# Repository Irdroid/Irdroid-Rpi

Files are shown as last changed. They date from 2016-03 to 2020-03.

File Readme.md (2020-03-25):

# Irdroid-Rpi Infrared Transceiver for Raspberry Pi

The latest gadget that we are working on is the Irdroid-Rpi Infrared Transceiver HAT / Add-on board for Raspberry Pi. The board provides Infrared Transmitter , Infrared Receiver and UEXT interconnect for Olimex sensors and boards designed with the UEXT connector. The board can be stacked on top of the Rpi board and you could turn your Rpi into a fully functional Infrared remote control for you home infrared consumer electronics. The Irdroid-Rpi is compatible with the LIRC/ Lirc GPIO driver for raspberry Pi and the LIRC utilities for recording and transmitting infrared signals can be used. The Irdroid-Rpi uses a optical IR amplification technique that allows to transmit high power IR signal by signal amplification after the IR light is emitted.

- Infrared Transceiver add-on / HAT for Raspberry Pi
- Infrared Transmitter @940nm with 10+ meters range
- Infrared Receiver up to 40khz and 10+ meters of receive range
- On-board UEXT Interconnect for connecting Olimex sensors and boards.
- Open Source Hardware.

### Version
1.0

### Installation Instructions

Detailed Installation Instructions https://irdroid.eu/wp-content/uploads/2020/03/Irdroid-Rpi-Installation-Guide.txt

### Grab a sample

You can grab a sample board from http://www.irdroid.eu/irdroid-rpi-infrared-transceiver-raspberry-pi/
### Tech

The Irdroid-Rpi infrared transceiver for Raspberry Pi is also designed with the possibility to connect sensors and boards from Olimex (http://www.olimex.com) by using the on-board UEXT connector, designed by Olimex. You can check here what sensors are supported https://www.olimex.com/Products/Components/Sensors/ .

### Todos

 - Add holders for the infrared leds in schematic
 
### Updates

Irdroid-Rpi now has a DT Overlay support via the on-board eeprom that now ships with every board. Once attached to a Raspberry Pi, the Irdroid-Rpi Hat will be recognized automatically, it will set the board inputs and outputs, and it will load the appropriate Kernel LIRC-RPI drivers. This feature improoves user experience and it provides plug-n-play support for the Product. The user will only have to install lircd (if not shipped by default with the distribution used).

The Irdroid-Rpi board details such as Vendor and Product IDs are available in 

/proc/device-tree/hat

To query Product & Vendor use:

$ more product  

$ more vendor

License
----
GPL 2.0

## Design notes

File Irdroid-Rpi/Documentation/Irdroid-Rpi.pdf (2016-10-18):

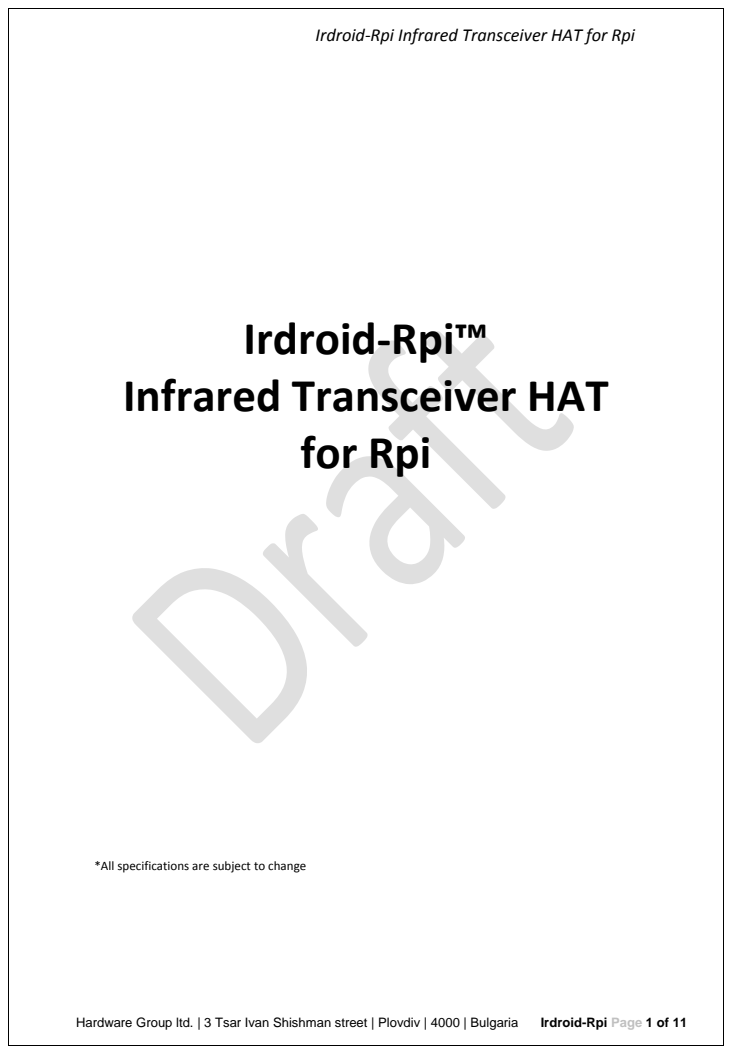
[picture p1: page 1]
Hardware Group ltd. | 3 Tsar Ivan Shishman street | Plovdiv | 4000 | Bulgaria; Irdroid-Rpi Page 1 of 11; for Rpi

Irdroid-Rpi Infrared Transceiver HAT for Rpi

Irdroid-Rpi™
Infrared Transceiver HAT

*All specifications are subject to change

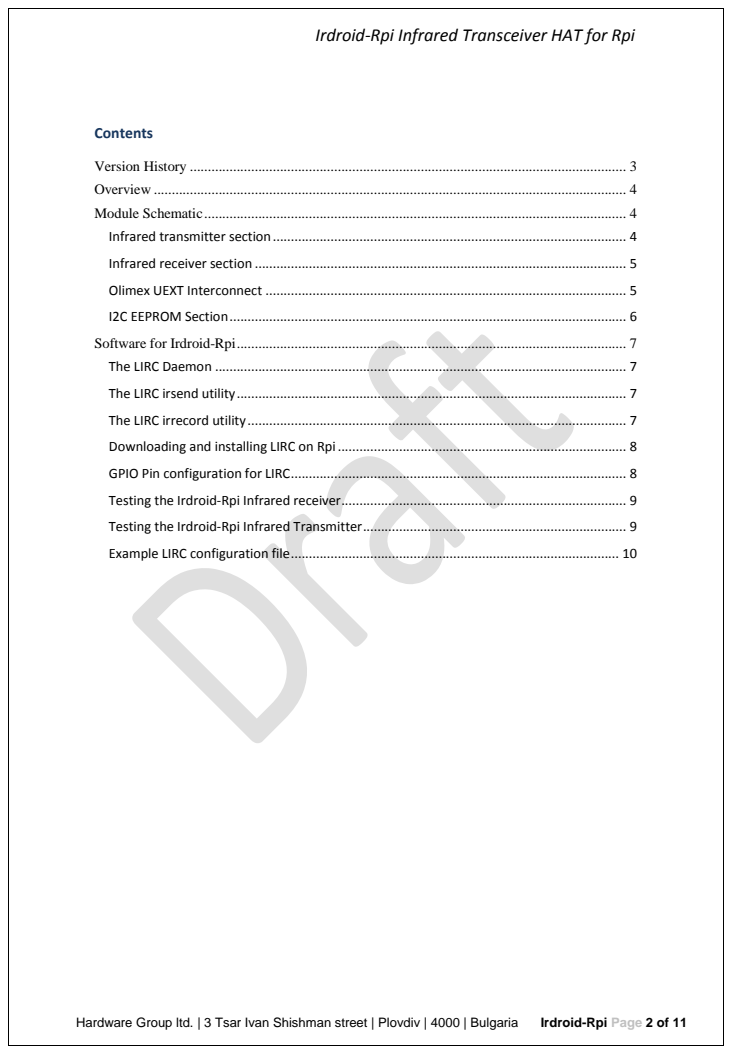
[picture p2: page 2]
Hardware Group ltd. | 3 Tsar Ivan Shishman street | Plovdiv | 4000 | Bulgaria; Irdroid-Rpi Page 2 of 11; Contents

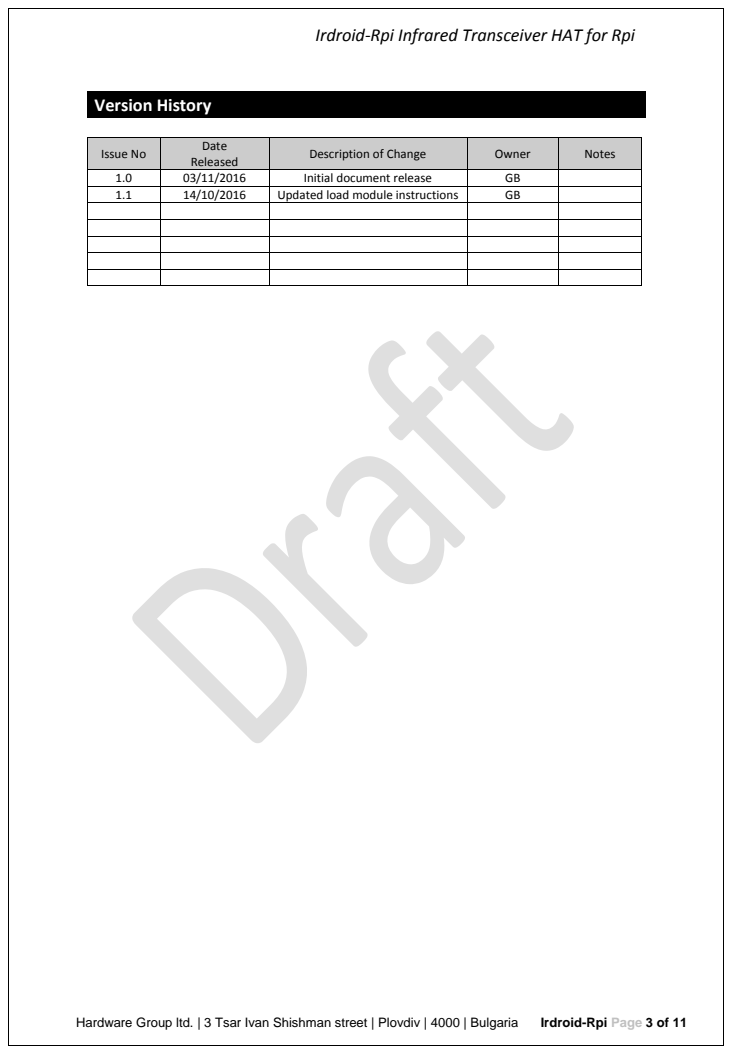
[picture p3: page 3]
Hardware Group ltd. | 3 Tsar Ivan Shishman street | Plovdiv | 4000 | Bulgaria; Irdroid-Rpi Page 3 of 11; Version History

Issue No | Date Released | Description of Change | Owner | Notes

1.0 | 03/11/2016 | Initial document release | GB
1.1 | 14/10/2016 | Updated load module instructions | GB

Hardware Group ltd. | 3 Tsar Ivan Shishman street | Plovdiv | 4000 | Bulgaria Irdroid-Rpi Page 4 of 11

Overview

The Irdroid-Rpi™ is a Infrared Transceiver stackable board or the so called HAT for Raspberry Pi . The Irdroid-Rpi™ allows both transmitting and receiving of infrared signals. The Irdroid-Rpi™ Infrared transmitter part is wired with three powerful infrared LEDs which emit infrared signals @ the commonly used infrared wavelength of 940nm. The module is designed and uses optical signal amplification, which combines the Infrared light emitted by the three infrared led's and significantly increases the infrared transmitting range.

The board interface with the Raspberry Pi is a 2x20 pin female header connector. Two GPIOs are used to control the Transmitter and Receiver part. The board also provides an Interface to the Olimex development boards and sensors via the Olimex's UEXT connector. The connector is wired following the Olimex recommendations for wiring a UEXT Host. The UEXT interconnect provides 2 Serial interfaces ( 1xUART and 1xSPI ), 1 I2C interface and 3.3V supply.
The Irdroid-Rpi™ board also has a place for a I2C EEPROM memory which is optional and not installed by default. The Irdroid-Rpi™ board in combination with LIRC for raspberry Pi can be used to control your home infrared consumer electronics like TVs, DVDs, Air-conditioners and even more.

Module Schematic

Below are the sections from the schematic responsible for the different actions like, Infrared transmitting, infrared receiving, I2C EEPROM and Olimex UEXT Interconnect section.

Infrared transmitter section

The image on the left shows the infrared transmitter section. The transmitter is powered by the Rpi 5V supply pins. We have envisaged alternative power supply in case the user decides to alter the schematic or change Infrared Leds. The jumper J2 is normally shorted and the Infrared Transmitter section is supplied with 5V DC from the Rpi board. There is a possibility to supply the board with a external 5V power supply by disconnecting jumper J2 and shorting the "EXT" jumper. As mentioned above the schematic allows for optical amplification of the transmitted infrared signal which increases the infrared range. The Infrared transmitter is controlled by the Rpi pin 11 (GPIO17).

Hardware Group ltd. | 3 Tsar Ivan Shishman street | Plovdiv | 4000 | Bulgaria Irdroid-Rpi Page 5 of 11

Infrared receiver section

The Infrared Receiver section consist of custom infrared receiver IC and it is supplied via the Raspberry Pi 3.3V power supply.

The infrared receiver IC can receive infrared signals @ up to 40khz which is the most common frequency used for consumer electronics infrared remote control.

The Infrared receiver IC DATA output pin is wired to the RPI pin 12 (GPIO18).

If required the user could de-solder and use a different Infrared Receiver IC of his choice.

Olimex UEXT Interconnect

The Irdroid-Rpi™ Infrared Transceiver HAT is equipped with a Olimex UEXT connector that would allow the users to connect various sensors and devices available for purchase from Olimex website - http://www.olimex.com .

The Olimex UEXT is wired for HOST mode which means that the UART RX/TX pins should be crossed at device end of the connection.

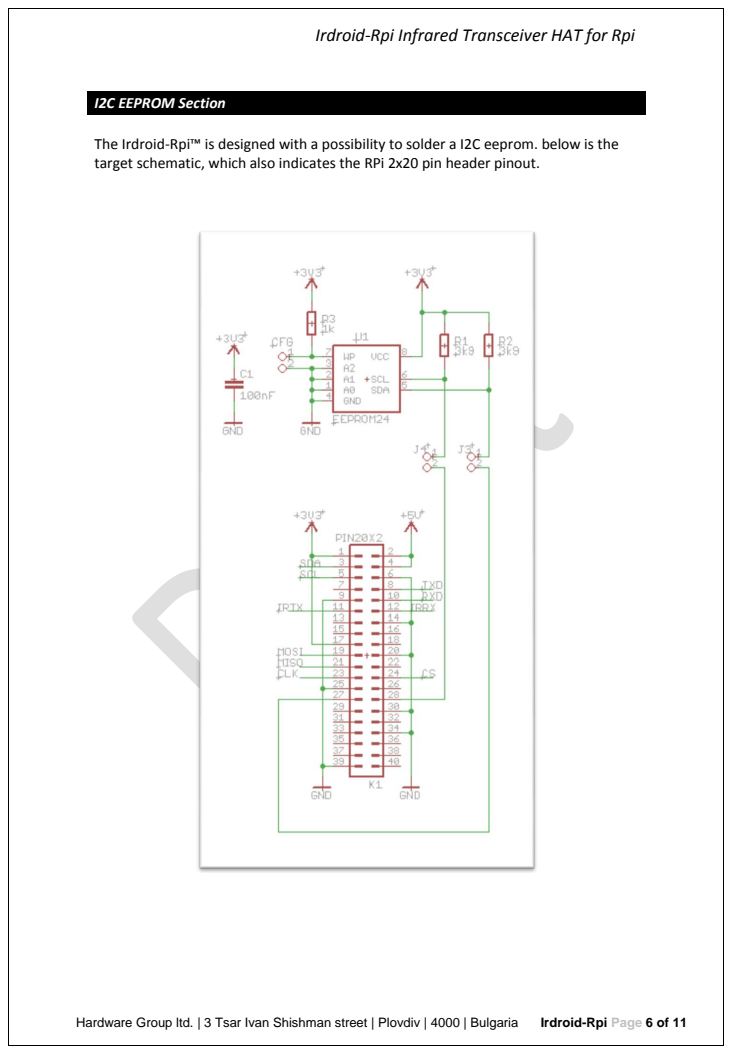
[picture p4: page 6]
Hardware Group ltd. | 3 Tsar Ivan Shishman street | Plovdiv | 4000 | Bulgaria; Irdroid-Rpi Page 6 of 11; I2C EEPROM Section

The Irdroid-Rpi™ is designed with a possibility to solder a I2C eeprom. below is the
target schematic, which also indicates the RPi 2x20 pin header pinout.

Hardware Group ltd. | 3 Tsar Ivan Shishman street | Plovdiv | 4000 | Bulgaria Irdroid-Rpi Page 7 of 11

Software for Irdroid-Rpi

The Irdroid-Rpi Infrared Transceiver HAT is designed for Rpi and the software that is commonly used is LIRC (Linux Infrared Remote control - see http://www.lirc.org). By using LIRC the user gets access to more than 2000+ already digitized infrared remote control codes that are in the LIRC database of supported remotes. The LIRC Software package is available for Almost any distribution of Linux. In this Manual we will describe the case of using the Linux Distribution for Rpi - Raspbian.

A detailed information and howtos for lirc can be found @ http://www.lirc.org .

The LIRC software packages has a number of utilities responsible for different actions like infrared transmitting, infrared receiving , serving the data to a socket.

The LIRC Daemon

The LIRC Daemon is a Linux daemon that runs as a process in linux and takes care of the data received via the device drivers and routes that data to a TCPIP Socket. It also listens for commands sent via Socket on a Specific port. The Lirc daemon runs in the background and it provides an interface to the infrared remote control application (LIRC Client). There are many Lirc clients , for Android , IOS, Linux and Windows.

The LIRC irsend utility

The irsend utility is used to transmit infrared commands to your target infrared equipment to be controlled like TVs , STBs , Air-con etc. The utility communicates with the LIRC daemon. The Utility has the following example syntax:

> irsend SEND_ONCE SAMSUNG_TV power

The above command send the command "power" for Device "Samsung_TV" and send it once with no repeat.

The Device should be available in the LIRC configuration file in order for the above command to be executed.

The LIRC irrecord utility

The program will allow you to record infrared commands from your existing remote control and create a LIRC configuration file for this particular remote control.

In order to use it you should make sure that the lircd is not working. Simply issue:

> sudo killall lircd

Hardware Group ltd. | 3 Tsar Ivan Shishman street | Plovdiv | 4000 | Bulgaria Irdroid-Rpi Page 8 of 11
> irrecord --list-namespace | grep KEY

Downloading and installing LIRC on Rpi

The LIRC software package can be downloaded and installed using the apt-get command :

> sudo apt-get install lirc
> sudo apt-get install lirc-x

GPIO Pin configuration for LIRC

The default gpio pins for the application are:

input pin for receiving infrared signals: PIN12/GPIO18
output pin for transmitting ir signals is : PIN11/GPIO17

The above default configuration is compatible with Irdroid-Rpi so practically you should not change it. There is a way to change the default pins by issuing the following command :

> modprobe lirc_rpi gpio_in_pin=18 gpio_out_pin=17

If the modprobe gives you an error , that the module cant be loaded due to the fact that the device is missing, then edit the file /boot/config.txt and uncomment the "dtoverlay=lirc-rpi" , save the changes and reboot your raspberry Pi . After the above changes you should have a /dev/lirc0 device, and you should be able to load the lirc_rpi module.

You could also edit the /etc/modules and change the pins there :

lirc_dev
lirc_rpi gpio_in_pin=18 gpio_out_pin=17

Edit your /etc/lirc/hardware.conf file as follows: > sudo su
> cd /etc/lirc
> sudo /leafpad hardware.conf
or
> sudo /leafpad /etc/lirc/hardware.conf

######################################################## # /etc/lirc/hardware.conf

# Arguments which will be used when launching lircd LIRCD_ARGS="--uinput --listen"

Hardware Group ltd. | 3 Tsar Ivan Shishman street | Plovdiv | 4000 | Bulgaria Irdroid-Rpi Page 9 of 11

# Don't start lircmd even if there seems to be a good config file # START_LIRCMD=false

# Don't start irexec, even if a good config file seems to exist.

# START_IREXEC=false

# Try to load appropriate kernel modules LOAD_MODULES=true

# Run "lircd --driver=help" for a list of supported drivers. DRIVER="default"

# usually /dev/lirc0 is the correct setting for systems using udev DEVICE="/dev/lirc0"

MODULES="lirc_rpi"
# Default configuration files for your hardware if any LIRCD_CONF=""

LIRCMD_CONF=""
5 of 9

Restart lircd so it picks up these changes:
sudo /etc/init.d/lirc restart

Testing the Irdroid-Rpi Infrared receiver

Once the the configurations described above are completed you can test the Infrared Receiver. To do that you need to stop the LIRC daemon by issuing the following command:

> sudo /etc/init.d/lirc stop
> sudo modprobe lirc_rpi
> sudo mode2 -d /dev/lirc0

the aboe commands first stop the lirc daemon , then it loads the lirc_rpi device driver module to the linux kernel and finally runs the program mode2 to show the mark - space of an infrared singal.

Now you could point a remote control toward the Irdroid-Rpi and press some buttons. You should be able to see similar output in the console as below:

space 402351
pulse 135
space 7085
pulse 85
space 2903

Testing the Irdroid-Rpi Infrared Transmitter

In order to test the Irdroid-Rpi infrared transmitter part you need to get a lirc configuration file for the target infrared equipment to be controlled . You can try

Hardware Group ltd. | 3 Tsar Ivan Shishman street | Plovdiv | 4000 | Bulgaria Irdroid-Rpi Page 10 of 11 searching in the LIRC database of remotes available at http://lirc.sf.net/remotes .
You could also generate a lirc conf file by recording the buttons of your remote control.

# You must stop lirc to free up /dev/lirc0 by issuing the following command

> sudo /etc/init.d/lirc stop
# Create a new remote control configuration file (using /dev/lirc0) and save the output to ~/lircd.conf

> irrecord -d /dev/lirc0 ~/lircd.conf

# Make a backup of the original lircd.conf file

>sudo mv /etc/lirc/lircd.conf /etc/lirc/lircd_original.conf

# Copy over your new configuration file

>sudo cp ~/lircd.conf /etc/lirc/lircd.conf

# Start up lirc again

>sudo /etc/init.d/lirc start

Once you’ve completed a remote configuration file save/add it to /etc/lirc/lircd.conf

Now you can use the irsend application that comes with the LIRC package for linux and you can issue a command using the syntax below:

> irsend SEND_ONCE Remote_Name Remote_Button

You could also download other remote control configuration files from the database of existing digitized remotes available at http://lirc.sf.net/remotes.

Example LIRC configuration file

The LIRC configuration file is used to store remote control codes either in RAW space pulse format or decoded HEX values, depending on the remote control protocol. Below is a example configuration file for TESY home panel heater unit.

# Please make this file available to others

# by sending it to <lirc@bartelmus.de>

# this config file was automatically generated

# using lirc-0.9.0(IRToy) on Thu Sep 17 21:47:15 2015 #

# contributed by

# brand: | Tesy

# model no. of remote control:

# devices being controlled by this remote: #

begin remote

name Tesy
bits | 16
flags SPACE_ENC
eps | 30
aeps | 100

Hardware Group ltd. | 3 Tsar Ivan Shishman street | Plovdiv | 4000 | Bulgaria | Irdroid-Rpi Page 11 of 11
header | 8969 4395
one | 599 1607
zero | 599 | 489
ptrail | 604
repeat | 8981 2156
pre_data_bits | 16
pre_data | 0xFF
gap | 39670
repeat_gap | 95433
toggle_bit_mask 0x0
| begin codes
power | 0x50AF
plus | 0x20DF
minus | 0xE01F
timer | 0xF807
temp | 0x08F7
end codes

end remote

As you can see there are specific section for every remote in this file which means that you can have multiple remotes defined in lircd.conf file .

The "begin remote" section defines the section start for a new remote control and the "end remote" section end for the remote . You can have as many remotes as you want defined in a single configuration file.

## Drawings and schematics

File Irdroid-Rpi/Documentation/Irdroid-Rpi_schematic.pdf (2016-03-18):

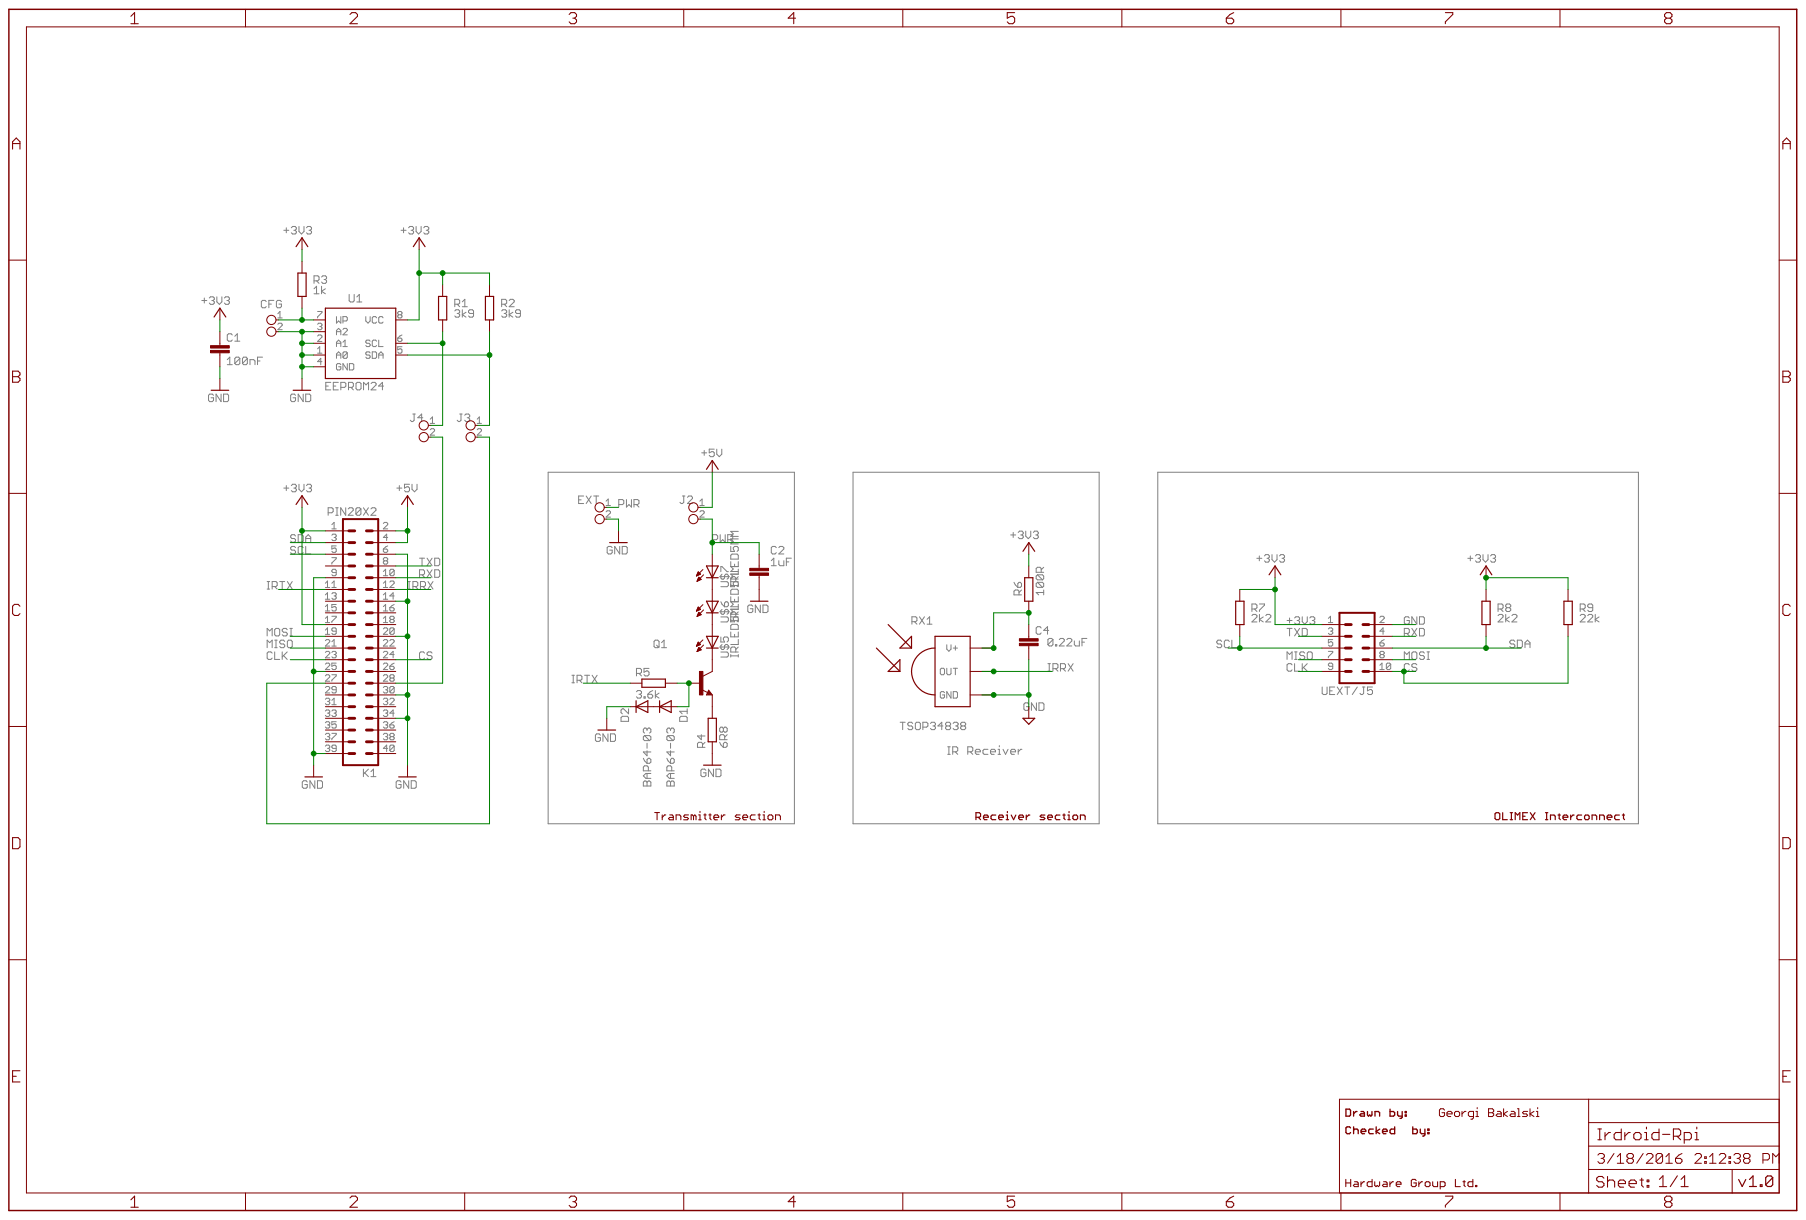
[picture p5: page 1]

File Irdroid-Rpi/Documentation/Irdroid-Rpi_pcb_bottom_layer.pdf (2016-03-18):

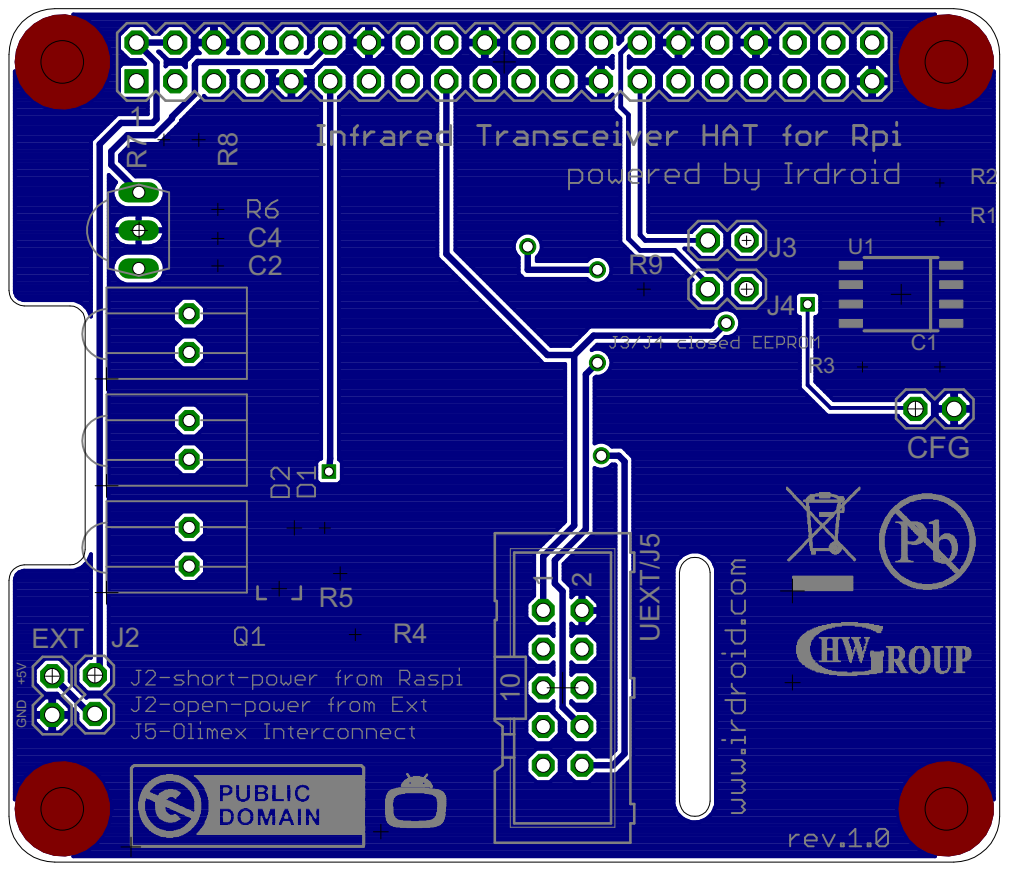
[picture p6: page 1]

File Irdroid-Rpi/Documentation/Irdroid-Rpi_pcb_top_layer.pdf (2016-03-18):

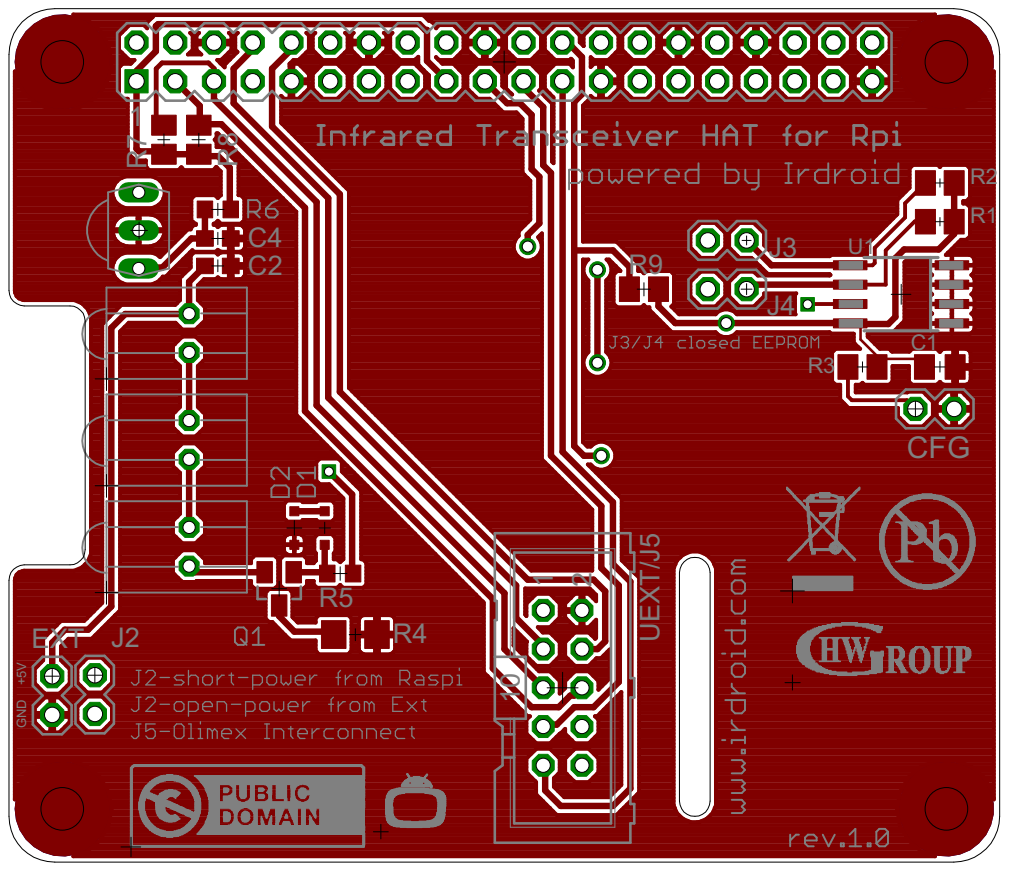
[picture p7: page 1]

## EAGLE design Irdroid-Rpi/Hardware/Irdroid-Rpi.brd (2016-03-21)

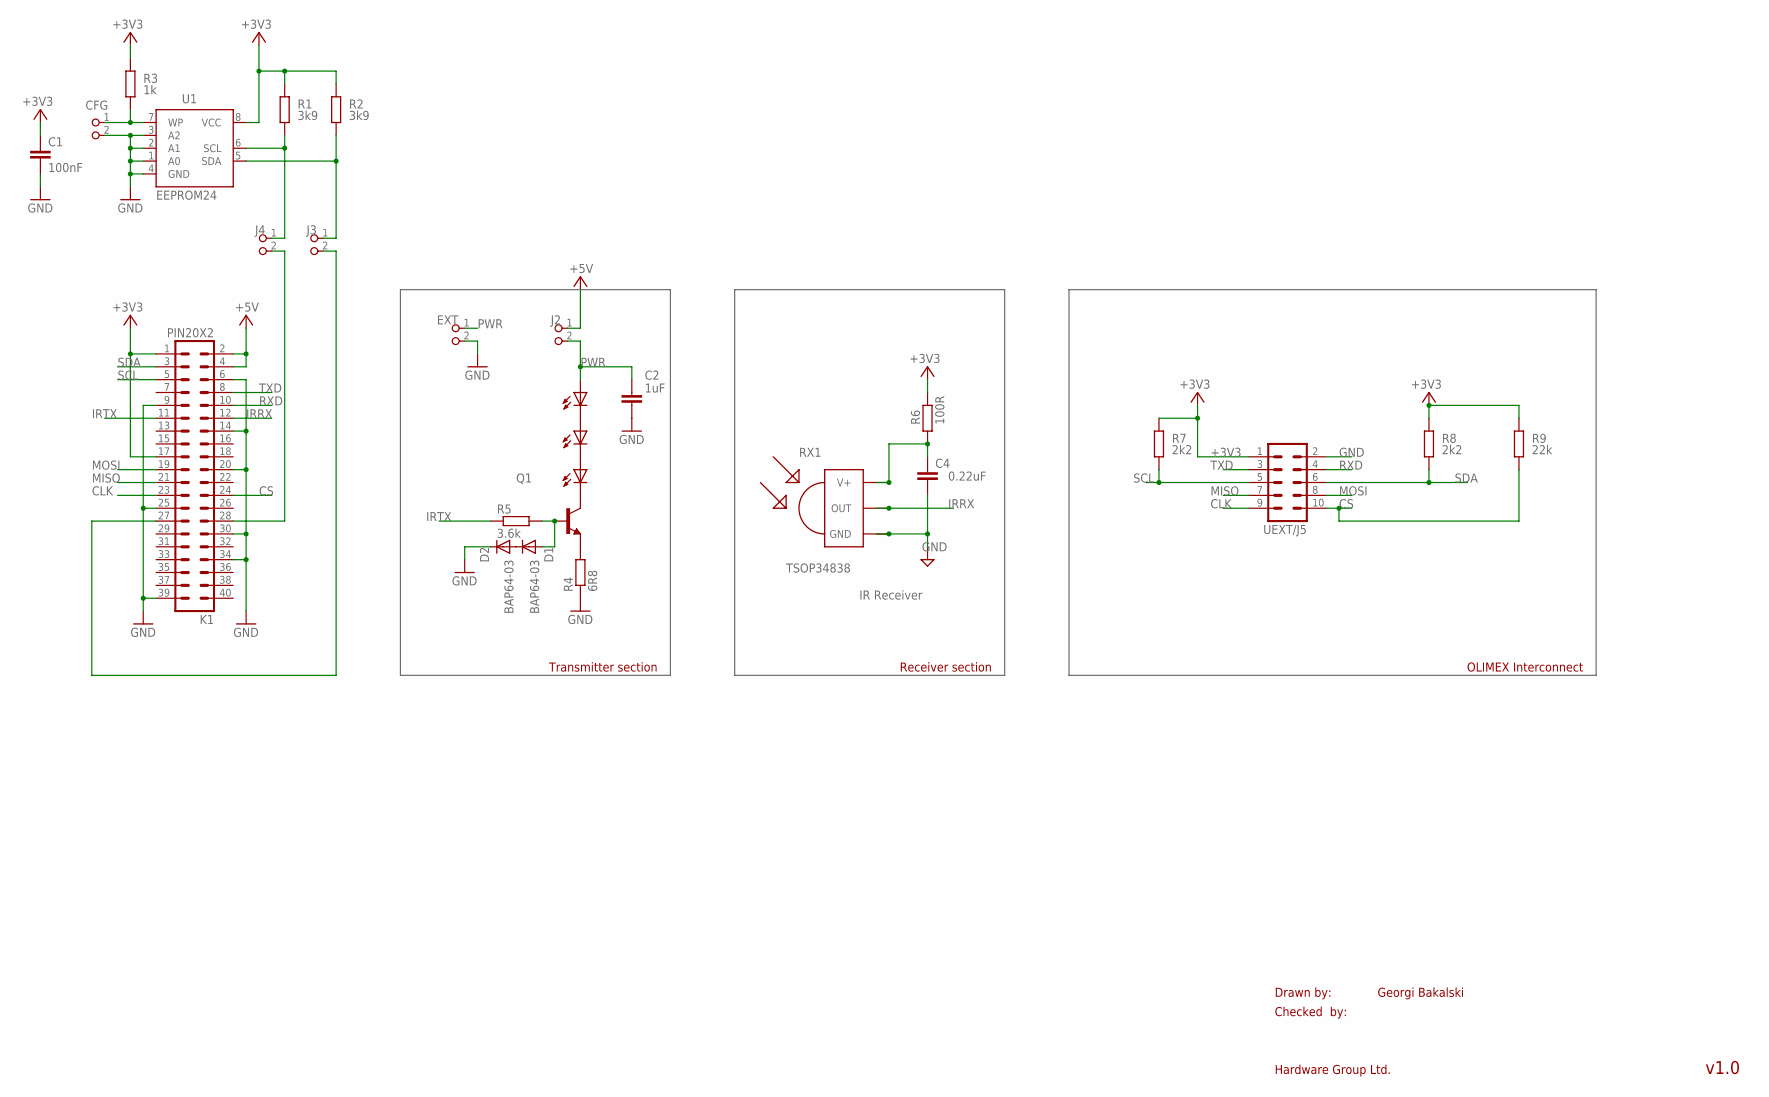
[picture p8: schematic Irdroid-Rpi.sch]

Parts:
C1: 100nF; C0805K
C2: 1uF; C603@1
C4: 0.22uF; C603
CFG: PIN2_100; PIN_W_2
D1, D2: BAP64-03; DO323
EXT: PIN2_100; PIN_W_2
J2, J3, J4: PIN2_100; PIN_W_2
K1: PIN20X2; PIN_20X2
Q1: TRANSISTOR_BJT_NPN-SOT-23-BCE; SOT-23
R1, R2: 3k9; M0805; TOLERANCE 5%
R3: 1k; M0805; TOLERANCE 5%
R4: 6R8; R1206
R5: 3.6k; R0603
R6: 100R; R603
R7, R8: 2k2; M0805; TOLERANCE 5%
R9: 22k; M0805; TOLERANCE 5%
RX1: TSOP34838; TSOP18XX
U1: EEPROM24; SOIC8
U$5, U$6, U$7: IRLED5MM; IRLED_HOLDER
UEXT/J5: ML10

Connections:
+3V3: C1.1, K1.1, K1.17, R1.2, R2.2, R3.2, R6.2, R7.2, R8.2, R9.2, U1.8 (VCC), UEXT/J5.1
+5V: J2.1, K1.2, K1.4
CLK: K1.23, UEXT/J5.9
CS: K1.24, R9.1, UEXT/J5.10
GND: C1.2, C2.2, C4.2, CFG.2, D2.C, EXT.2, K1.6, K1.9, K1.14, K1.20, K1.25, K1.30, K1.34, K1.39, R4.1, RX1.GND, U1.1 (A0), U1.2 (A1), U1.3 (A2), U1.4 (GND), UEXT/J5.2
IRRX: K1.12, RX1.OUT
IRTX: K1.11, R5.1
MISO: K1.21, UEXT/J5.7
MOSI: K1.19, UEXT/J5.8
unnamed: J4.2, K1.28
unnamed: J3.2, K1.27
unnamed: CFG.1, R3.1, U1.7 (WP)
unnamed: Q1.3 (E), R4.2
unnamed: Q1.2 (C), U$5.K (C)
unnamed: U$5.A, U$6.K (C)
unnamed: U$6.A, U$7.K (C)
unnamed: D1.A, Q1.1 (B), R5.2
unnamed: D1.C, D2.A
unnamed: C4.1, R6.1, RX1.VCC (V+)
unnamed: J4.1, R1.1, U1.6 (SCL)
unnamed: J3.1, R2.1, U1.5 (SDA)
PWR: C2.1, EXT.1, J2.2, U$7.A
RXD: K1.10, UEXT/J5.4
SCL: K1.5, R7.1, UEXT/J5.5
SDA: K1.3, R8.1, UEXT/J5.6
TXD: K1.8, UEXT/J5.3

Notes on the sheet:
Drawn by:
Checked by:
Hardware Group Ltd.
Georgi Bakalski
v1.0
Transmitter section
RX1
TSOP34838
IR Receiver
Receiver section
OLIMEX Interconnect

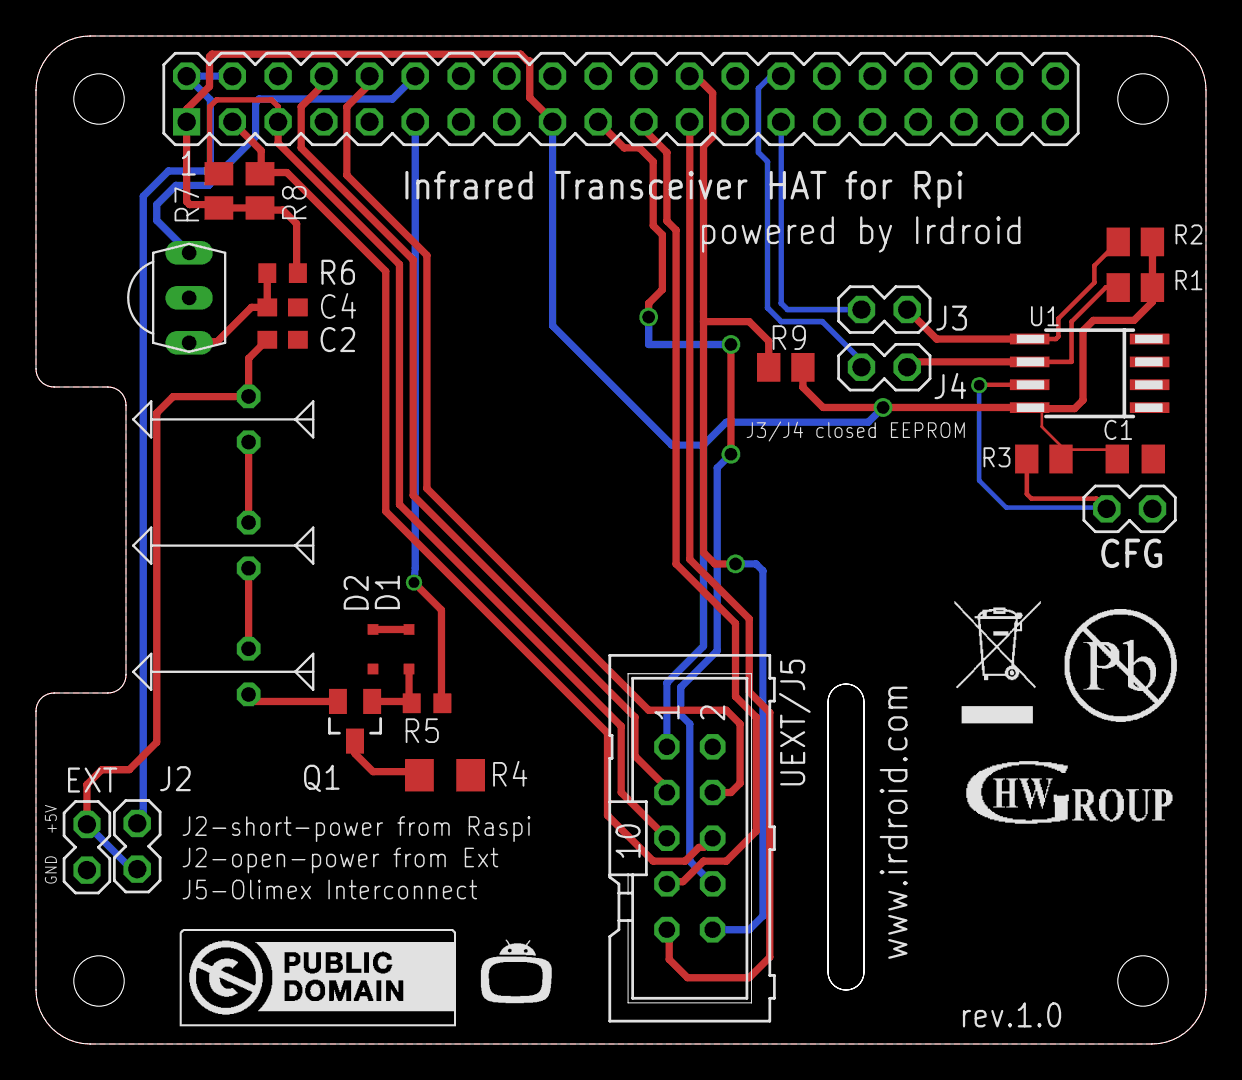
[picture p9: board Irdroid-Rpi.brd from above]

Board: 2 copper layers, 65.0 x 56.0 mm, 31 parts (0 on the bottom side), 26 nets.

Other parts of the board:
U$1: LOGO_CC-0
U$2: IRDROIDLOGO
U$3: TRASH
U$4: HWGROUP

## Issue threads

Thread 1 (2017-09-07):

Parts list?

nardev, 2017-09-07:
hello,

nice project, wondering what is the transistor used for IR diodes and why did you need BAP64 there?

thnx

Irdroid, 2017-09-11:
Parts list is included in the Eagle Schematic file

Irdroid, 2017-09-11:
The Transistor could be any NPN SMT transistor that can handle > 250mA of current

nardev, 2017-09-11:
thank you very much....

nardev, 2017-09-11:
and BAP64?

Irdroid, 2017-09-12:
yes, BAP64 SMD

nardev, 2017-09-13:
:D the question was "why did you need BAP64 there?"

nardev, 2017-09-13:
SOrry, didn't notice it was grounded.. i got it now...

Closed 2017-09-12.

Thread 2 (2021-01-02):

Installation instructions

jonathanschneider, 2021-01-02:
The installation instructions referenced in README.md apply to Raspbian Buster. I think this should be mentioned.

jonathanschneider, 2021-01-02:
Also, how does one know if the update regarding DT overlay applies to ones hat?

Irdroid, 2021-01-02:
Hi Jonathan,

These are the updated instructions:

jonathanschneider, 2021-01-02:
That’s the instructions I mean. They apply to Raspian Buster but it doesn’t say that anywhere.

jonathanschneider, 2021-01-02:
And in the „Updates“ section please define „now“.

Irdroid, 2021-01-02:
> That’s the instructions I mean. They apply to Raspian Buster but it doesn’t say that anywhere.
> I believe the process for Raspbian Stretch is different.

It should be the same as long as you update Stretch to it's latest possible kernel version

jonathanschneider, 2021-01-02:
Okay. I have not tested it but I had found this [post by the author of the patch](https://www.raspberrypi.org/forums/viewtopic.php?f=28&t=235256&sid=35cf78d5fa0a104456c95f6070b600db) before and he describes different steps for Buster and Stretch.

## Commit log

2016-03-18 Initial Release 1.0
    [Irdroid-Rpi.brd, Irdroid-Rpi.sch]
2016-03-18 Added Irdroid-Rpi Schematic and PCB pdf prints
2016-03-21 Changed and updated the Infrared LED library with a plastic 90 degrees holder.
    [Irdroid-Rpi.brd, Irdroid-Rpi.sch]
2016-03-21 Added board Gerbers
2018-05-25 DeviceTree overlay support via onboard EEPROM
    DeviceTree overlay support via onboard EEPROM
